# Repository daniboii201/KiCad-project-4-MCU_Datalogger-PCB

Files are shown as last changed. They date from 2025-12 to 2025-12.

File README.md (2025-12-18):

# KiCad project #4: MCU Datalogger PCB
This is my fourth PCB design created using KiCad. Unlike my previous projects, this design focuses on building a microcontroller-based datalogger circuit. The board is intended for logging sensor data to external storage, making it useful for IoT and embedded applications. This project includes two PCB versions: a 2-layer design for cost efficiency and a 4-layer design for improved signal integrity and compact routing.









## Features
• Microcontroller-based datalogger for sensor data acquisition

• Support for external storage (microSD card interface)

• Power regulation for stable MCU operation

• Two PCB versions: 2-layer (budget-friendly) and 4-layer (optimized for EMI and routing)

• Designed for low-power applications and modular sensor connectivity

### Components
• Microcontroller: ATmega328P-AU

• EEPROM: 2 x 24LC2025

• Real-Time Clock: DS1337S_T_R

• Oscillators:

  – 32.768 kHz (RTC timing)

  – 16 MHz (MCU clock)

• Capacitors:

  – 2 x 22 pF
  
  – 2 x 0.1 µF
  
  – 1 x 100 nF
  
• Resistors:

  – 3 x 10 kΩ
  
  – 2 x 4.7 kΩ
  
  – 2 x 330 Ω
  
• LEDs: 2 for status indication

• Battery: For RTC backup

• Pin headers: For programming and sensor interfaces

### Characteristics:
• Two PCB versions:

  – 2-layer: Cost-effective design for basic applications, suitable for simple routing and lower manufacturing costs.

  – 4-layer: Optimized for signal integrity with dedicated ground and power planes, reduced EMI, and improved reliability. Includes mostly SMD components for a compact footprint, silkscreen labels for easy assembly, mounting holes for stability, and copper pours for thermal management.

### How It Works:
The MCU Datalogger PCB is designed to collect sensor data, process it, and store it reliably. Here’s the workflow:

1. Power Management

The board includes a voltage regulator that converts the input supply (battery or external source) to a stable 3.3 V or 5 V rail for the microcontroller and peripherals. Decoupling capacitors near the MCU and SD card ensure clean power and reduce noise.

2. Data Acquisition

Sensors connect via standard interfaces such as I²C, SPI, or UART. The microcontroller periodically reads sensor values based on programmed intervals or triggers.

3. Data Logging

The MCU writes the collected data to a microSD card using the SPI protocol. This allows large storage capacity and easy data retrieval for analysis.

4. Clock & Timing

A crystal oscillator provides accurate timing for logging intervals and communication protocols, ensuring data consistency.

5. PCB Layer Benefits

  • 2-layer version: Simple and cost-effective, suitable for basic applications.

  • 4-layer version: Includes dedicated ground and power planes for better signal integrity, reduced EMI, and improved reliability in noisy environments.

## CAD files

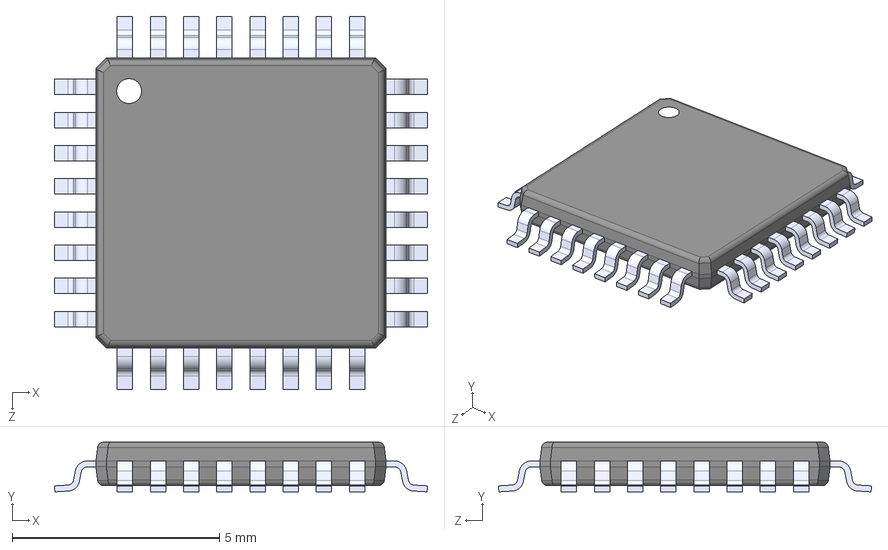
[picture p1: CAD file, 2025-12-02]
ATMEGA328P_AU/ATMEGA328P-AU.step
9.00 x 1.20 x 9.00 mm

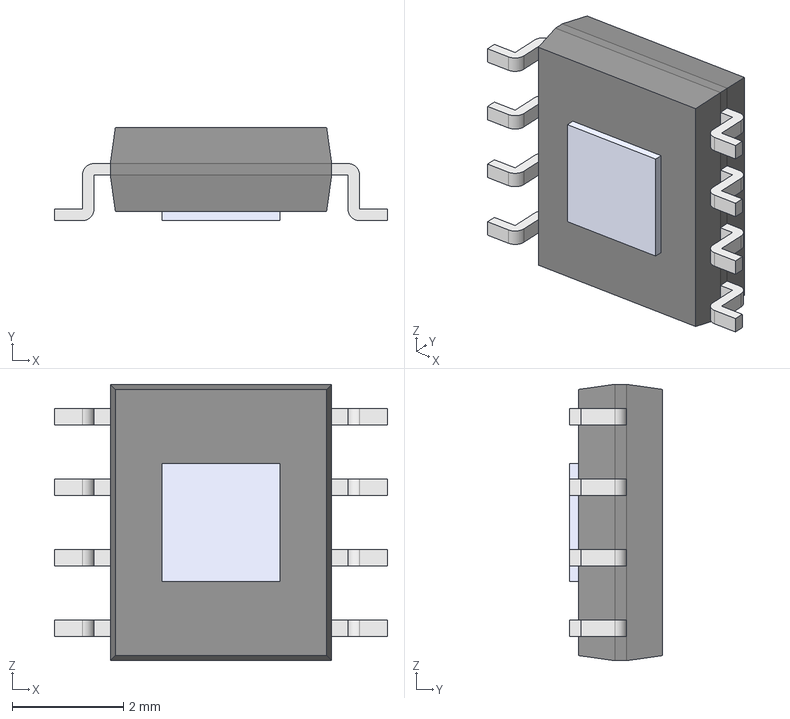
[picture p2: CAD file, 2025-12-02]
DS1337S_T_R/DS1337S_T_R.step
6.00 x 1.68 x 4.98 mm
Body001 (Mirror #1) x 4
XY-plane x 12
X-axis x 12

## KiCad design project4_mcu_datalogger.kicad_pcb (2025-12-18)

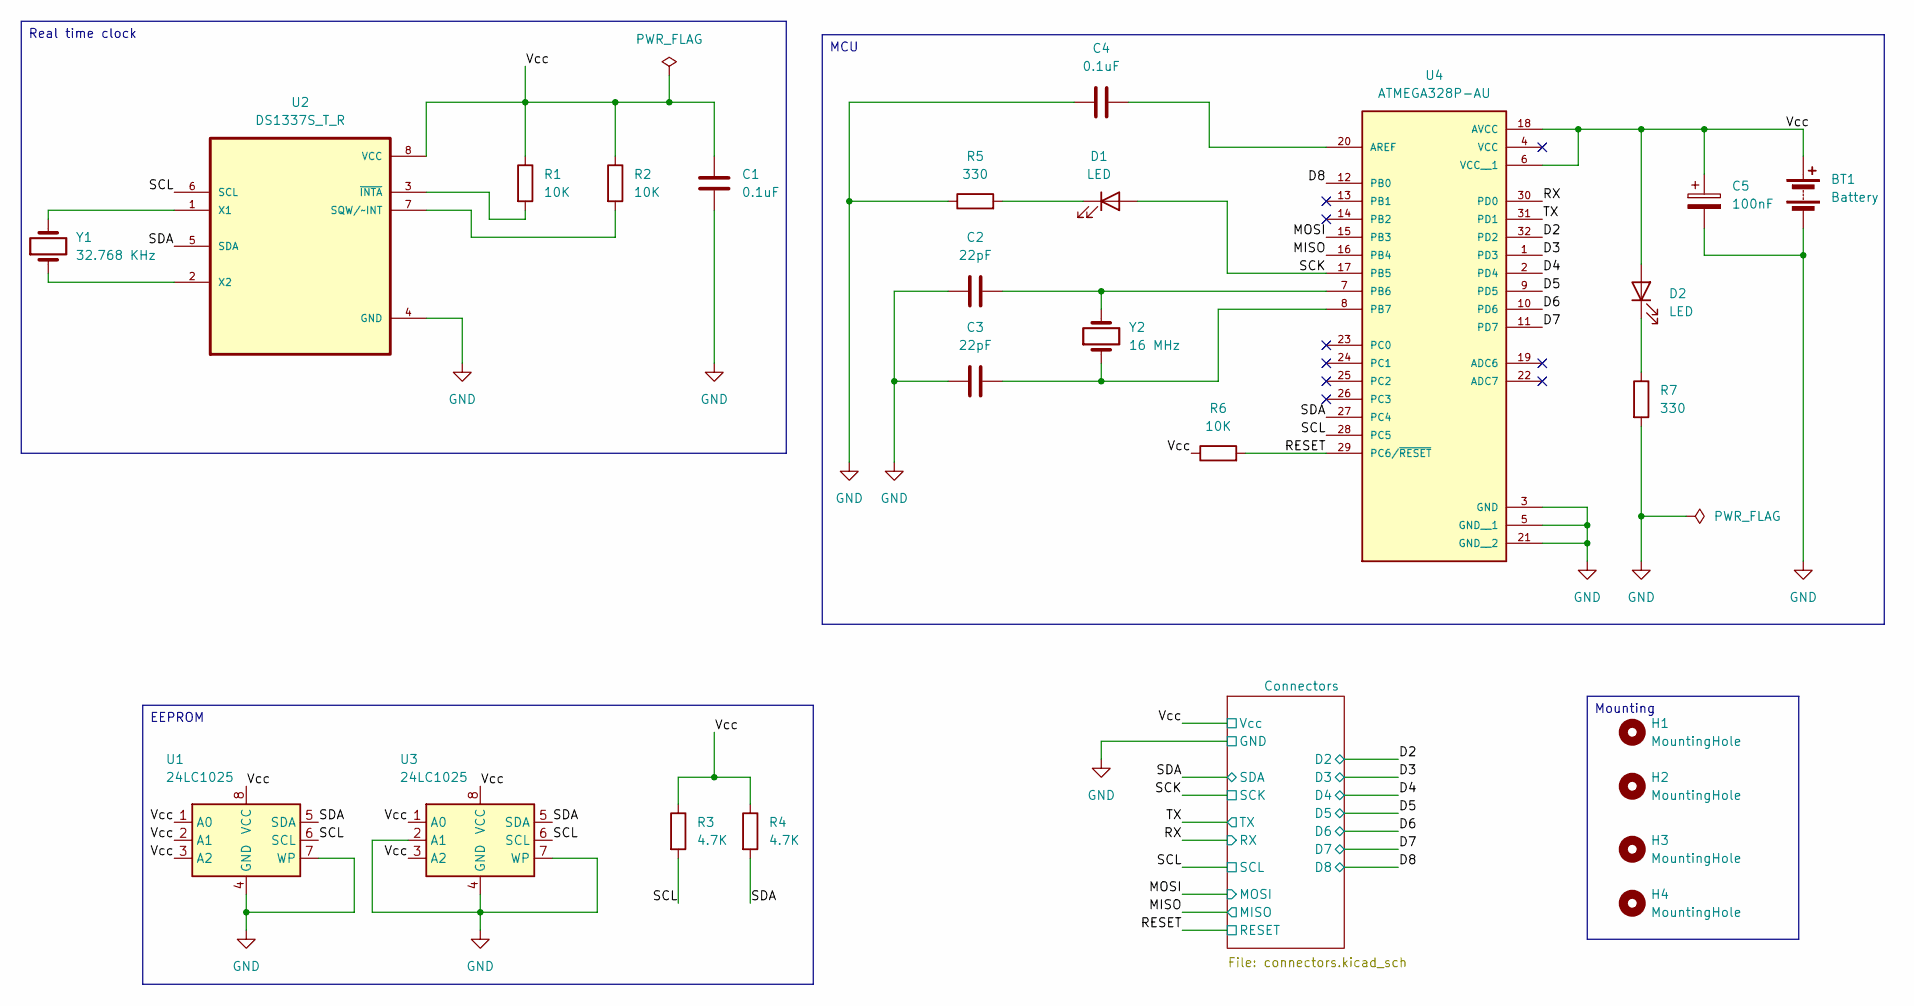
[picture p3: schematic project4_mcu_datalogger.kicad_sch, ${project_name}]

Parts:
BT1: Battery; PinHeader_1x02_P2.54mm_Vertical
C1, C4: 0.1uF; C_0805_2012Metric
C2, C3: 22pF; C_0805_2012Metric
C5: 100nF; C_0805_2012Metric
D1, D2: LED; LED_0805_2012Metric
H1, H2, H3, H4: MountingHole; MountingHole_2.1mm
R1, R2, R6: 10K; R_0805_2012Metric
R3, R4: 4.7K; R_0805_2012Metric
R5, R7: 330; R_0805_2012Metric
U1, U3: 24LC1025; SOIC-8_5.3x5.3mm_P1.27mm
U2: DS1337S_T_R; SOIC127P600X175-8N
U4: ATMEGA328P-AU; QFP80P900X900X120-32N; PARTREV 8271A
Y1: 32.768 KHz; Crystal_SMD_Abracon_ABM3-2Pin_5.0x3.2mm_HandSoldering
Y2: 16 MHz; Crystal_SMD_Abracon_ABM3-2Pin_5.0x3.2mm_HandSoldering

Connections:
/D2: U4.32 (PD2); also elsewhere on the board
/D3: U4.1 (PD3); also elsewhere on the board
/D4: U4.2 (PD4); also elsewhere on the board
/D5: U4.9 (PD5); also elsewhere on the board
/D6: U4.10 (PD6); also elsewhere on the board
/D7: U4.11 (PD7); also elsewhere on the board
/D8: U4.12 (PB0); also elsewhere on the board
/MISO: U4.16 (PB4); also elsewhere on the board
/MOSI: U4.15 (PB3); also elsewhere on the board
/RESET: R6.2, U4.29 (PC6/~RESET); also elsewhere on the board
/RX: U4.30 (PD0); also elsewhere on the board
/SCK: D1.2 (A), R3.2, U1.6 (SCL), U2.6 (SCL), U3.6 (SCL), U4.17 (PB5), U4.28 (PC5); also elsewhere on the board
/SDA: R4.2, U1.5 (SDA), U2.5 (SDA), U3.5 (SDA), U4.27 (PC4); also elsewhere on the board
/TX: U4.31 (PD1); also elsewhere on the board
/Vcc: BT1.1 (+), C1.1, C5.1, D2.2 (A), R1.1, R2.1, R3.1, R4.1, R6.1, U1.1 (A0), U1.2 (A1), U1.3 (A2), U1.8 (VCC), U2.8 (VCC), U3.1 (A0), U3.3 (A2), U3.8 (VCC), U4.6 (VCC__1), U4.18 (AVCC); also elsewhere on the board
GND: BT1.2 (-), C1.2, C2.1, C3.1, C4.1, C5.2, R5.1, R7.2, U1.4 (GND), U1.7 (WP), U2.4 (GND), U3.2 (A1), U3.4 (GND), U3.7 (WP), U4.3 (GND), U4.5 (GND__1), U4.21 (GND__2); also elsewhere on the board
unnamed: D1.1 (K), R5.2
unnamed: D2.1 (K), R7.1
unnamed: R2.2, U2.7 (SQW/~INT)
unnamed: U2.1 (X1), Y1.2
unnamed: U2.2 (X2), Y1.1
unnamed: R1.2, U2.3 (~INTA)
unnamed: C4.2, U4.20 (AREF)
unnamed: C2.2, U4.7 (PB6), Y2.2
unnamed: C3.2, U4.8 (PB7), Y2.1

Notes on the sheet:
MCU
EEPROM
Real time clock
Mounting

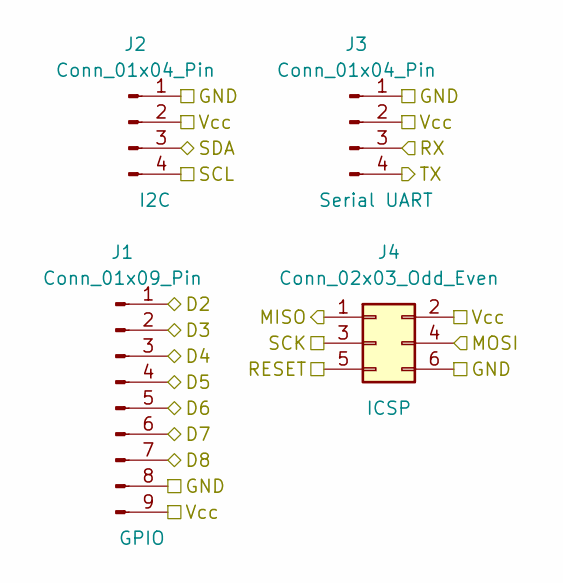
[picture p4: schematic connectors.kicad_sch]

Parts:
J1: Conn_01x09_Pin; PinHeader_1x09_P2.54mm_Vertical
J2, J3: Conn_01x04_Pin; PinHeader_1x04_P2.54mm_Vertical
J4: Conn_02x03_Odd_Even; PinHeader_2x03_P2.54mm_Vertical

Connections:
/D2: J1.1; also elsewhere on the board
/D3: J1.2; also elsewhere on the board
/D4: J1.3; also elsewhere on the board
/D5: J1.4; also elsewhere on the board
/D6: J1.5; also elsewhere on the board
/D7: J1.6; also elsewhere on the board
/D8: J1.7; also elsewhere on the board
/MISO: J4.1; also elsewhere on the board
/MOSI: J4.4; also elsewhere on the board
/RESET: J4.5; also elsewhere on the board
/RX: J3.3; also elsewhere on the board
/SCK: J2.4, J4.3; also elsewhere on the board
/SDA: J2.3; also elsewhere on the board
/TX: J3.4; also elsewhere on the board
/Vcc: J1.9, J2.2, J3.2, J4.2; also elsewhere on the board
GND: J1.8, J2.1, J3.1, J4.6; also elsewhere on the board

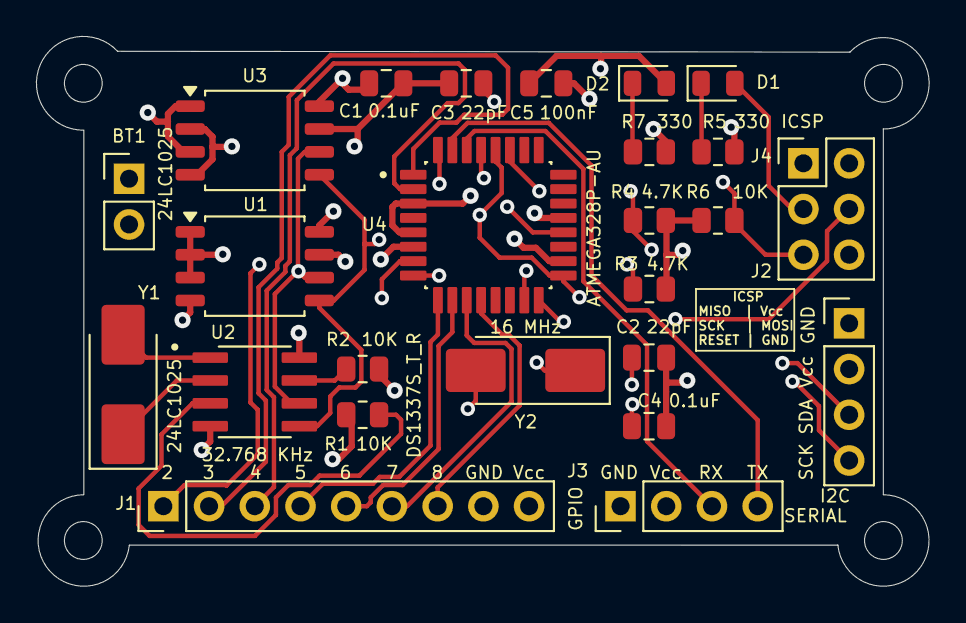
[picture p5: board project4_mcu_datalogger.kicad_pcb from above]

Board: 4 copper layers, 49.6 x 30.5 mm, 29 parts (0 on the bottom side), 25 nets.

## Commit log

2025-11-28 Update .gitignore to ignore gerbers folder
    [project4_mcu_datalogger.kicad_pcb, project4_mcu_datalogger.kicad_sch]
2025-11-28 Update .gitignore to ignore gerbers and backups folders
2025-11-28 Remove Gerber folder from repo but keep locally
2025-12-01 commit .kicad_pro
2025-12-01 Setup of EEschema for new project
    [project4_mcu_datalogger.kicad_sch]
2025-12-01 Have added required symbols to the schematic sheets
    [connectors.kicad_sch, project4_mcu_datalogger.kicad_sch]
2025-12-01 Changed locations of symbols
    [connectors.kicad_sch, project4_mcu_datalogger.kicad_sch]
2025-12-01 Added component values
    [connectors.kicad_sch, project4_mcu_datalogger.kicad_sch]
2025-12-02 Completed symbol to footprint associations
    [ATMEGA328P-AU.step, DS1337S_T_R.step, connectors.kicad_sch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]
2025-12-02 Completed wiring of main sheet
    [connectors.kicad_sch, project4_mcu_datalogger.kicad_sch]
2025-12-02 Completed wiring in the second sheet
    [connectors.kicad_sch, project4_mcu_datalogger.kicad_sch]
2025-12-02 Allocated GND and Vcc nets to the Power net class
    [connectors.kicad_sch]
2025-12-02 Completed comments
    [connectors.kicad_sch, project4_mcu_datalogger.kicad_sch]
2025-12-03 Setup Pcbnew
    [project4_mcu_datalogger.kicad_pcb]
2025-12-03 Completed placement of footprints
    [connectors.kicad_sch, project4_mcu_datalogger.kicad_pcb, project4_mcu_datalogger.kicad_sch]
2025-12-05 Completed PCB routing
    [connectors.kicad_sch, project4_mcu_datalogger.kicad_pcb, project4_mcu_datalogger.kicad_sch]
2025-12-05 Rework of PCB routing
    [project4_mcu_datalogger.kicad_pcb]
2025-12-05 Added copper fills and improved routing
    [project4_mcu_datalogger.kicad_pcb]
2025-12-08 Fixed outstanding issues
    [connectors.kicad_sch, project4_mcu_datalogger.kicad_pcb, project4_mcu_datalogger.kicad_sch]
2025-12-08 Added back silkscreen
    [project4_mcu_datalogger.kicad_pcb]
2025-12-08 Added missing 3d models to components
    [project4_mcu_datalogger.kicad_pcb]
2025-12-12 Completed 4-layer pcb routing
    [project4_mcu_datalogger.kicad_pcb]
2025-12-12 Completed v2 of pcb routing
    [project4_mcu_datalogger.kicad_pcb]
2025-12-12 Added gitattributes file to ignore PCB files during merge
2025-12-12 Fixed two defects in the schematic
    [connectors.kicad_sch, project4_mcu_datalogger.kicad_sch]
2025-12-18 Fixed net bugs in 4-layer version of the PCB
    [project4_mcu_datalogger.kicad_pcb]
2025-12-18 Completed 4-layer pcb
